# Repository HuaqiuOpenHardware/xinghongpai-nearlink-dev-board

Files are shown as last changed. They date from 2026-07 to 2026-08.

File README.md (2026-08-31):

<h1 align="center">Xinghongpai NearLink Dev Board</h1>

<p align="center"><strong>星鸿派 · WS63V100 / Hi3863 星闪开源开发板</strong></p>

<p align="center">
  <a href="README_EN.md">English</a> |
  <strong>简体中文</strong>
</p>

<p align="center">
  <a href="https://p.eda.cn/d-1328625634846441472">原始项目</a> ·
  <a href="hardware/">硬件设计</a> ·
  <a href="hardware/bom/">BOM</a> ·
  <a href="firmware/">固件示例</a> ·
  <a href="downloads/MANIFEST.md">资料校验</a>
</p>

<p align="center">
  🛠️ <a href="https://github.com/HuaqiuOpenHardware/xinghongpai-nearlink-dev-board/issues/new/choose">提交问题</a>
  &nbsp;·&nbsp;
  🤝 <a href="CONTRIBUTING.md">参与贡献</a>
  &nbsp;·&nbsp;
  ⭐ <a href="https://github.com/HuaqiuOpenHardware/xinghongpai-nearlink-dev-board">收藏项目</a>
</p>

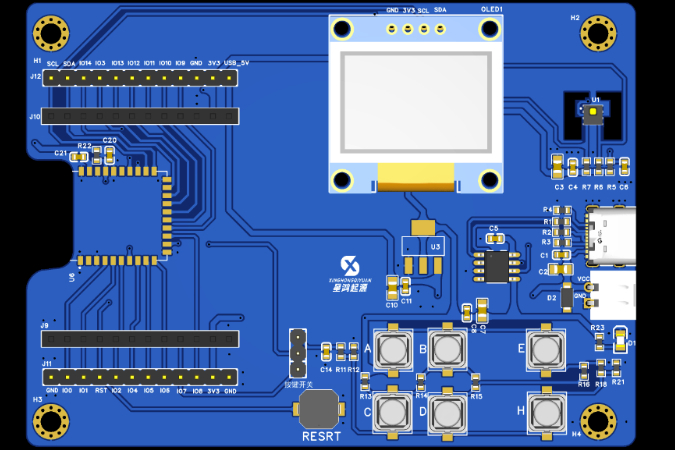
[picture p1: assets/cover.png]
星鸿派 WS63V100 星闪开源开发板


星鸿派是一款基于海思 **WS63V100 / Hi3863** 平台的开源开发板，支持 **星闪 NearLink（SLE）**、Wi-Fi 和 BLE，面向 OpenHarmony 学习、物联网原型、智能家电、环境监测与嵌入式教学。本仓库直接开放 KiCad 原理图与 PCB、BOM，以及 OpenHarmony / Hi3863 固件示例。

> 本仓库整理自华秋开源硬件社区公开项目。硬件许可证的具体 CERN-OHL 版本尚待项目方确认；复刻、修改或商用前请先阅读[许可证说明](#许可证说明)。

## 一眼看懂

| 项目 | 内容 |
| --- | --- |
| 主控平台 | HiSilicon WS63V100 / Hi3863 系列 |
| 无线连接 | NearLink SLE、Wi-Fi、BLE |
| 软件方向 | OpenHarmony / Hi3863 示例工程 |
| 板载资源 | 0.96 寸 OLED、6 个用户按键、复位按键、温湿度模块 |
| 硬件资产 | KiCad 工程、原理图、PCB、BOM |
| PCB 信息 | 约 96 mm × 70 mm，双层板（来自原项目页） |
| 适用人群 | 嵌入式开发者、创客、学生、教师与硬件研究者 |

## 开放资料

| 想找什么 | 仓库入口 | 当前状态 |
| --- | --- | --- |
| 原理图与 PCB 源文件 | [`hardware/kicad/`](hardware/kicad/) | 已提交，可直接查看与下载 |
| BOM 物料清单 | [`hardware/bom/`](hardware/bom/) | 已提交 XLSX |
| OpenHarmony / Hi3863 示例 | [`firmware/examples/`](firmware/examples/) | 已提交；依赖外部 SDK，不是独立工程 |
| 硬件与固件使用边界 | [`hardware/README.md`](hardware/README.md)、[`firmware/README.md`](firmware/README.md) | 已说明 |
| 原始资料来源与校验值 | [`downloads/MANIFEST.md`](downloads/MANIFEST.md) | 已记录 URL、大小和 SHA256 |
| 项目事实与来源 | [`PROJECT_FACTSHEET.md`](PROJECT_FACTSHEET.md) | 已整理 |
| 导入时的改动 | [`CHANGES_FROM_ORIGINAL.md`](CHANGES_FROM_ORIGINAL.md) | 已记录 |

原项目页提到 Gerber 文件，但首次导入使用的 PCB 下载包中没有独立 Gerber 制造文件。本仓库不把“页面提到”表述成“仓库已经提供”。

## 快速开始

### 查看或修改硬件

1. 打开 [`hardware/kicad/`](hardware/kicad/) 并下载 `.kicad_pro`、`.kicad_sch` 与 `.kicad_pcb` 文件。
2. 使用 KiCad 打开工程；复刻前同时核对原理图、PCB、[`BOM`](hardware/bom/) 和板卡实物版本。
3. 生成 Gerber、钻孔文件或贴片文件前，重新执行 ERC/DRC，并人工确认封装、替代料、电源与射频设计。

### 使用固件示例

1. 先阅读 [`firmware/README.md`](firmware/README.md)，确认示例并非可独立编译的完整 SDK。
2. 准备与示例匹配的 OpenHarmony / Hi3863（WS63）SDK 环境。
3. 从 GPIO、定时器、AHT20、OLED 等基础示例开始，再进入 Wi-Fi、TCP/UDP 与综合应用示例。
4. 提交问题时请提供 SDK / OpenHarmony 版本、示例目录、完整编译日志和板卡版本。

> 仓库尚未提供经过维护者复核的统一编译命令，因此这里不编造“一键编译”步骤。欢迎通过 Issue 或 Pull Request 补充可复现的环境说明。

## 固件示例方向

仓库中已有线程、定时器、互斥锁、信号量、消息队列、GPIO、AHT20、ADC、OLED、Wi-Fi、TCP/UDP，以及风扇、火焰检测、交通灯、继电器、温湿度等示例。具体文件以 [`firmware/examples/`](firmware/examples/) 为准。

推荐起点：

- [`11_aht20`](firmware/examples/11_aht20/)：AHT20 温湿度传感器
- [`13_adclight`](firmware/examples/13_adclight/)：ADC 光线采集
- [`14_easy_wifi`](firmware/examples/14_easy_wifi/)：Wi-Fi 连接与热点
- [`201_oled`](firmware/examples/201_oled/)：OLED 显示

## 仓库结构

```text
.
├── .github/                 # Issue 与 Pull Request 模板
├── assets/                 # 封面与实物图片
├── downloads/              # 原始下载地址、文件大小与 SHA256
├── firmware/
│   └── examples/           # OpenHarmony / Hi3863 固件示例
├── hardware/
│   ├── bom/                # BOM 物料清单
│   └── kicad/              # KiCad 原理图与 PCB 工程
├── LICENSES/               # 混合内容的许可证说明
├── CONTRIBUTING.md
├── PROJECT_FACTSHEET.md
├── README.md
└── README_EN.md
```

## 许可证说明

这个仓库包含硬件、固件和第三方资料，不能用一个未经确认的许可证覆盖全部内容：

- 原项目页的许可证字段显示 **CERN Open Hardware License**，但没有注明 CERN-OHL-S、W 或 P 等具体版本。
- 原项目页正文另有 Apache 2.0 与商用表述，两处口径并不完全一致。
- 多个固件文件保留了 HiHope Open Source Organization、HiSilicon 等来源的 Apache-2.0 版权头。
- 芯片文档、SDK、工具和原始压缩包可能适用各自的上游条款。

复刻、再分发、批量制造或商业化前，请阅读 [`LICENSE`](LICENSE) 与 [`LICENSES/README.md`](LICENSES/README.md)，并向项目方确认硬件许可证的准确版本。不要删除文件内已有的版权与许可证声明。

## 参与项目

- 硬件问题：使用 Hardware Issue 模板，注明板卡版本、测量结果、照片与复现步骤。
- 固件问题：使用 Firmware Issue 模板，注明 SDK / OpenHarmony 版本和完整日志。
- 提交修改：先阅读 [`CONTRIBUTING.md`](CONTRIBUTING.md)，并说明 BOM、硬件、固件和许可证影响。
- 安全问题：不要在公开 Issue 中提交 Wi-Fi 密码、密钥或生产设备凭据，详见 [`SECURITY.md`](SECURITY.md)。

## 来源与搜索别名

原始项目：华秋开源硬件社区「[星鸿派-星闪开发板](https://p.eda.cn/d-1328625634846441472)」。

相关名称：星闪、NearLink、SLE、SparkLink、WS63、WS63V100、Hi3863、HiSilicon、OpenHarmony、open-source hardware、development board、schematic、PCB、BOM、KiCad。

---

## 获取帮助与加入交流

如果你正在查找星闪开发资料、搭建 OpenHarmony / Hi3863 环境、复刻硬件，或希望交流项目使用与二次开发，可以添加 **华秋开源硬件小助手**。

添加后可获取：

- 星鸿派项目资料导航与更新提醒
- 开源硬件交流群入群方式
- 社区活动、试用与共创信息
- Issue 提交和项目反馈指引

<p align="center">
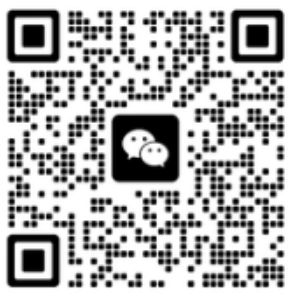
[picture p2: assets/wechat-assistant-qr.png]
华秋开源硬件小助手微信二维码
  
</p>

<p align="center"><strong>微信扫码添加小助手</strong></p>

<p align="center">添加时建议备注“星鸿派”，方便更快对接相关资料与交流群。</p>

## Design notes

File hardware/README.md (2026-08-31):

# Hardware | 硬件设计

This directory contains the KiCad hardware source files and BOM for the Xinghongpai NearLink development board.

本目录保存星鸿派 WS63V100 / Hi3863 星闪开发板的 KiCad 原理图、PCB 与 BOM。制造或修改前请同时核对原理图、PCB、BOM 和实际板卡版本。

## Files

- `kicad/*.kicad_pro`: KiCad project.
- `kicad/*.kicad_sch`: Schematic source.
- `kicad/*.kicad_pcb`: PCB layout source.
- `bom/BOM_Board1_Schematic1_2026-01-09.xlsx`: Bill of materials.

## Notes

The p.eda.cn page describes a 96 mm x 70 mm two-layer PCB. Gerber files were mentioned on the page but were not present as separate files in the downloaded PCB zip used for this import.

Before fabrication:

1. Open the complete project rather than a single schematic or PCB file.
2. Re-run ERC/DRC with the KiCad version used for your modification.
3. Verify footprints, alternative parts, connector orientation, power rails and RF-related layout against the intended board revision.
4. Generate fresh Gerber, drill, position and BOM outputs from the reviewed source. Do not treat generated files from an unknown revision as authoritative.
5. Record material substitutions and board changes in the Pull Request.

The presence of source files is not evidence that a modified board has been fabricated or electrically validated. Clearly label unverified derivatives.

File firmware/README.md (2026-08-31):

# Firmware Examples | 固件示例

The `examples/` directory contains OpenHarmony / Hi3863 sample applications from the original `02-程序源码.zip` package.

These examples reference an external OpenHarmony / HiSilicon WS63 SDK tree and are not expected to build standalone from this repository. Keep third-party SDKs outside this repo unless their license explicitly allows redistribution.

这些示例依赖仓库外部的 OpenHarmony / Hi3863（WS63）SDK，不能把本目录当成可独立编译的完整工程。仓库目前没有经过维护者复核的统一 SDK 版本和一键编译命令。

## Before using an example

1. Record the SDK and OpenHarmony version you are using.
2. Read the example's `BUILD.gn`, `CMakeLists.txt` or local README before copying it into an SDK tree.
3. Check GPIO, I2C, ADC, PWM and other pin assignments against your physical board revision.
4. Replace all network credentials with local test values and never commit real passwords or keys.
5. Capture the complete build command and log when reporting a problem.

## Suggested learning order

- Basic OS primitives: `00_thread`, `01_timer`, `03_mutex`, `04_semaphore`, `05_message`
- Board peripherals: `101_gpioled`, `11_aht20`, `13_adclight`, `201_oled`
- Networking: `14_easy_wifi`, `15_tcpclient`, `16_tcpserver`, `17_udpclient`, `18_udpserver`
- Integrated applications: directories in the `100`, `200` and `300` series

Directory names reflect the imported source package and do not imply that every example has been independently tested in this repository.

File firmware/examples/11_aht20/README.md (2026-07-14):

# 润和星闪派物联网开发套件--I2C（i2c_aht20）

hihope_illustration

[润和星闪派物联网开发套件](https://item.taobao.com/item.htm?id=816685710481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) 基于海思WS63E解决方案的一套软硬件组合的综合性开发套件。

wifi_iot

## 一、I2C API

| API名称 | 说明 |
| --- | --- |
| I2cInit (WifiIotI2cIdx id, unsigned int baudrate) | 用指定的波特速率初始化I2C设备 |
| I2cDeinit (WifiIotI2cIdx id) | 取消初始化I2C设备 |
| I2cWrite (WifiIotI2cIdx id, unsigned short deviceAddr, const WifiIotI2cData *i2cData) | 将数据写入I2C设备 |
| I2cRead (WifiIotI2cIdx id, unsigned short deviceAddr, const WifiIotI2cData *i2cData) | 从I2C设备中读取数据 |

## 二、Aht20 API

本样例提供了一个鸿蒙AHT20数字温湿度传感器驱动库，其功能如下：

* 使用Harmony OS的IoT硬件接口;
* 接口简洁易于使用、易于移植;
* 内置了测试程序，可直接进行测试;

| API名称 | 说明 |
| --- | --- |
| uint32_t AHT20_Calibrate(void) | 校准，成功返回0 |
| uint32_t AHT20_StartMeasure(void) | 触发测量，成功返回0 |
| uint32_t AHT20_GetMeasureResult(float* temp, float* humi) | 读取测量结果，成功返回0 |

## 三、如何编译

1. 将11_aht20目录复制到openharmony源码的`applications\sample\wifi-iot\app`目录下，
2. 修改openharmony源码的`applications\sample\wifi-iot\app\BUILD.gn`文件，将其中的 `features` 改为：

```
    features = [
        ...
        "11_aht20:i2c_demo",
        ...
    ]
```
3. 在`device\soc\hisilicon\ws63v100\sdk\build\config\target_config\ws63\config.py`文件中，找到`'ws63-liteos-app'`部分，在其`'ram_component'`中，添加以下代码：
```
"i2c_demo"
```

4. 在`device\soc\hisilicon\ws63v100\sdk\libs_url\ws63\cmake\ohos.cmake`文件中，找到`"ws63-liteos-app"`部分，在其`set(COMPONENT_LIST`部分，添加以下代码：
```
"i2c_demo"
```
5. 在openharmony sdk根目录目录执行：`rm -rf out && hb set -p nearlink_dk_3863 && hb build -f`

## 四、运行结果

烧录文件后，按下reset按键，程序开始运行，串口工具会输出测量后的温湿度数据

### 【套件支持】

##### 1. 套件购买  https://item.taobao.com/item.htm?id=816685710481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

##### 2. 技术资料

- Gitee码云网站（使用说明书、规格说明书、OpenHarmony开发案例等） **https://gitee.com/hihopeorg_group/near-link**
- fbb_ws63代码仓（SDK包、技术文档下载）**https://gitee.com/HiSpark/fbb_ws63**

##### 3. 互动交流
- 海思社区星闪专区-论坛 **https://developers.hisilicon.com/forum/0133146886267870001**

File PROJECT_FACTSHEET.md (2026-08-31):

# Project Factsheet

| Field | Value |
| --- | --- |
| Project | 星鸿派-星闪开发板 |
| English repo name | xinghongpai-nearlink-dev-board |
| Original URL | https://p.eda.cn/d-1328625634846441472 |
| Published on p.eda.cn | 2026-01-15 13:37:14 |
| Main controller | HiSilicon Hi3863 / WS63V100 series |
| Connectivity | Wi-Fi, BLE, SLE / NearLink |
| OS target | OpenHarmony |
| PCB | 96 mm x 70 mm, 2-layer |
| Hardware source | KiCad project, schematic and PCB |
| BOM | Included as XLSX |
| Firmware | OpenHarmony / Hi3863 examples |
| Page license field | CERN Open Hardware License |
| Page body license statement | Apache 2.0 |
| License status | Exact CERN-OHL hardware variant requires project-owner confirmation |
| Repository owner | HuaqiuOpenHardware |
| Repository | xinghongpai-nearlink-dev-board |

## Discovery aliases

星闪 / NearLink / SLE / SparkLink / WS63 / WS63V100 / Hi3863 / HiSilicon / OpenHarmony / development board / open-source hardware / schematic / PCB / BOM / KiCad

## Evidence boundary

This factsheet summarizes the imported project page and repository files. It does not claim independent validation of radio range, power consumption, environmental limits, firmware compatibility or manufacturing readiness.

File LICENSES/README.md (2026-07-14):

# License Notes

This repository is a mixed open hardware / firmware import from the public p.eda.cn project page for "星鸿派-星闪开发板".

## Hardware

The p.eda.cn license field states "CERN Open Hardware License". The specific CERN-OHL variant, such as S, W or P, was not provided in the page metadata captured for this import. Treat hardware redistribution as pending license-version confirmation before manufacturing or publishing modified derivatives.

## Firmware

Many firmware files include Apache License 2.0 headers from HiHope Open Source Organization and HiSilicon. The Apache-2.0 license text is included as `Apache-2.0.txt` when available.

## Original archives and vendor documents

`downloads/MANIFEST.md` records the public p.eda.cn download URLs and SHA256 checksums for the original packages. SDK and vendor documentation archives may contain third-party content; downstream users should follow the upstream terms included in those packages.

## Page inconsistency

The page content also says the project adopts Apache 2.0 for commercial reuse. Because the page-level license field and page body are not fully aligned for hardware licensing, this repository keeps the notices explicit instead of collapsing everything into one license.

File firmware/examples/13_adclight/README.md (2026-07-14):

# 润和星闪派物联网开发套件--ADC（光敏电阻）

hihope_illustration

[润和星闪派物联网开发套件](https://item.taobao.com/item.htm?id=816685710481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) 基于海思WS63E解决方案的一套软硬件组合的综合性开发套件。

wifi_iot

## 一、OLED与主控芯片引脚的对应关系

炫彩板光敏电阻对应核心板GPIO9(ADC2)

## 二、如何编译

1. 将13_adclight目录复制到openharmony源码的`applications\sample\wifi-iot\app`目录下，
2. 修改openharmony源码的`applications\sample\wifi-iot\app\BUILD.gn`文件，将其中的 `features` 改为：

```
    features = [
        ...
        "13_adclight:adc_light_demo",
        ...
    ]
```
3. 在`device\soc\hisilicon\ws63v100\sdk\build\config\target_config\ws63\config.py`文件中，找到`'ws63-liteos-app'`部分，在其`'ram_component'`中，添加以下代码：
```
"adc_light_demo"
```

4. 在`device\soc\hisilicon\ws63v100\sdk\libs_url\ws63\cmake\ohos.cmake`文件中，找到`"ws63-liteos-app"`部分，在其`set(COMPONENT_LIST`部分，添加以下代码：
```
"adc_light_demo"
```
5. 在openharmony sdk根目录目录执行：`rm -rf out && hb set -p nearlink_dk_3863 && hb build -f`

6. 如果编译失败，可以用串口助手，波特率设置为115200，发送AT指令(AT+SYSINFO\n)给开发板，如果返回的sdk版本低于SDK Version:1.10.102，需要替换一下adc相关的驱动文件，具体步骤参考adc_driver目录下替换文件步骤.txt

## 三、运行结果

烧录文件后，按下reset按键，程序开始运行，用手遮挡完全遮挡炫彩灯板上的光敏电阻，串口会打印一段时间的高电平数值，移开遮挡，串口会打印低电平数值。

### 【套件支持】

##### 1. 套件购买  https://item.taobao.com/item.htm?id=816685710481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

##### 2. 技术资料

- Gitee码云网站（使用说明书、规格说明书、OpenHarmony开发案例等） **https://gitee.com/hihopeorg_group/near-link**
- fbb_ws63代码仓（SDK包、技术文档下载）**https://gitee.com/HiSpark/fbb_ws63**

##### 3. 互动交流
- 海思社区星闪专区-论坛 **https://developers.hisilicon.com/forum/0133146886267870001**

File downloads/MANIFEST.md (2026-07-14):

# Original Download Manifest

Downloaded from the public p.eda.cn project page on 2026-07-14.
Large original archives are listed here instead of committed to Git history.

| Suggested local filename | Original filename | Bytes | SHA256 | Source |
| --- | --- | ---: | --- | --- |
| `01-xinghongpai-pcb.zip` | 01-星鸿派PCB.zip | 2084257 | `b765e80b18654c105c2079579242a03b7792638cc49ba510ce236c5e1ef5bfdf` | https://file1.huaqiu.com/web3/M00/48/C5/wKgZO2ly4ZGACJmXAB_Nofk7ZP8226.zip |
| `bom-2026-01-09.xlsx` | BOM_Board1_Schematic1_2026-01-09.xlsx | 13194 | `7dfdf15d19e44aa473998f1a41473c7713a62fab5a959dcc6f8dc81abec134c2` | https://file1.huaqiu.com/web3/M00/47/61/wKgZPGloVEqAFqJ2AAAzikkFFWU75.xlsx |
| `02-firmware-source.zip` | 02-程序源码.zip | 588959 | `ba52f00a5f157a4ca00100fa9ff8f750dab6bbe26f38795a7b5fd48a5d6bdcf7` | https://file1.huaqiu.com/web3/M00/48/C3/wKgZPGly4ECAKcdRAAj8n2G8QeY032.zip |
| `03-software-materials.zip` | 03-软件资料.zip | 11491575 | `581733ee7b2d679af3b7a50aa9e28f6ba4d0a471a8af4fe804eafc4ad1d431a7` | https://file1.huaqiu.com/web3/M00/48/C5/wKgZO2ly4FqANQWVAK9Y94BYe_Y757.zip |
| `04-course-documents.zip` | 04-课程文档.zip | 5325991 | `e247d37dae3311ed46612e51cb38a603ee40b18a3dc62cd049522f13e51aa0c9` | https://file1.huaqiu.com/web3/M00/48/C3/wKgZPGly4GCAD1TOAFFEpx-0sTY659.zip |
| `05-hispark-sdk-non-oh.zip` | 05-Hispark官方SDK方式（非OH）.zip | 3311853 | `8d67a0d5b3440f28f9779a69982212e576bd974ca63119f511d35917c8b14484` | https://file1.huaqiu.com/web3/M00/48/C3/wKgZPGly4GiAC9zeADKI7RaFW04333.zip |
| `06-ws63-official-documents.zip` | 06-WS63系列官方文档.zip | 22855597 | `9caa4624ff83f06b7a05d71526a10d64285c71d976740c0ff7624067d7fd837c` | https://file1.huaqiu.com/web3/M00/48/C3/wKgZPGly4JOAHNAmAVy_rQVX9NY285.zip |

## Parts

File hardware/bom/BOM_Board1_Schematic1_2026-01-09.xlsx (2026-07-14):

No. | Quantity | Comment | Designator | Footprint | Value | Manufacturer Part | Manufacturer | Add into BOM | Convert to PCB | Supplier | Supplier Part
1 | 6 | TS665WS 250gf | A,B,C,D,E,H | SW-SMD_L6.0-W6.0-LS6.6 |  | TS665WS 250gf | SHOU HAN(首韩) | yes | yes | LCSC | C6798384
2 | 7 | 100nF | C1,C4,C5,C8,C11,C14,C20 | C0603 | 100nF | CL10B104KB8NNNC | SAMSUNG(三星) | yes | yes | LCSC | C1591
3 | 4 | 22uF | C2,C3,C7,C10 | C0805 | 22uF | CL21A226MAQNNNE | SAMSUNG(三星) | yes | yes | LCSC | C45783
4 | 2 | 4.7uF | C6,C21 | C0603 | 4.7uF | CL10A475KO8NNNC | SAMSUNG(三星) | yes | yes | LCSC | C19666
5 | 1 | WAFER-XH254WZ-2AM | CN6 | CONN-TH_2P-P2.50_WAFER-XH254WZ-2A |  | WAFER-XH254WZ-2AM | HANBO(汉博) | yes | yes | LCSC | C22751831
6 | 1 | NCD0805R1 | D1 | LED0805-R-RD |  | NCD0805R1 | 国星光电 | yes | yes | LCSC | C84256
7 | 1 | SMF12CA | D2 | SOD-123FL_L3.0-W1.8-LS3.7-BI |  | SMF12CA | Littelfuse(美国力特) | yes | yes | LCSC | C1851360
8 | 4 | TP | H1,H2,H3,H4 | HOLE-3.2X5.5 |  |  |  | yes | yes
9 | 2 | KH-2.54FH-1X12P-H8.5 | J9,J10 | HDR-TH_12P-P2.54-V-F |  | KH-2.54FH-1X12P-H8.5 | kinghelm(金航标) | yes | yes | LCSC | C2905419
10 | 2 | X6511WV-12H-C60D30 | J11,J12 | HDR-TH_12P-P2.54-V-M |  | X6511WV-12H-C60D30 | XKB Connection(中国星坤) | yes | yes | LCSC | C725944
11 | 1 | HS96L03W2C03 | OLED1 | OLED-TH_L27.8-W27.2-P2.54_C9900033791 |  | HS96L03W2C03 | HS(汉昇) | yes | yes | LCSC | C5248080
12 | 2 | 0Ω | R1,R2 | R0603 | 0Ω | 0603WAF0000T5E | UNI-ROYAL(厚声) | yes | yes | LCSC | C21189
13 | 2 | 5.1kΩ | R3,R4 | R0603 | 5.1kΩ | 0603WAF5101T5E | UNI-ROYAL(厚声) | yes | yes | LCSC | C23186
14 | 1 | 470Ω | R5 | R0603 | 470Ω | 0603WAF4700T5E | UNI-ROYAL(厚声) | yes | yes | LCSC | C23179
15 | 2 | 10kΩ | R6,R7 | R0603 | 10kΩ | 0603WAF1002T5E | UNI-ROYAL(厚声) | yes | yes | LCSC | C25804
16 | 1 | 1kΩ | R11 | R0603 | 1kΩ | 0603WAF1001T5E | UNI-ROYAL(厚声) | yes | yes | LCSC | C21190
17 | 2 | 100kΩ | R12,R22 | R0603 | 100kΩ | 0603WAF1003T5E | UNI-ROYAL(厚声) | yes | yes | LCSC | C25803
18 | 7 | 300Ω | R13,R14,R15,R16,R18,R21,R23 | R0603 | 300Ω | 0603WAF3000T5E | UNI-ROYAL(厚声) | yes | yes | LCSC | C23025
19 | 2 | 4.7kΩ | R19,R20 | R0603 | 4.7kΩ | 0603WAF4701T5E | UNI-ROYAL(厚声) | yes | yes | LCSC | C23162
20 | 1 | OS4D502110 | RESRT | SW-SMD_L6.0-W6.0-P6.00-LS6.8 |  | OS4D502110 | SAMZO(三佐) | yes | yes | LCSC | C42402921
21 | 1 | AHT20 | U1 | SENSOR-SMD_L3.0-W3.0-P1.00-BR |  | AHT20 | 广州奥松 | yes | yes | LCSC | C2757850
22 | 1 | CH340N | U2 | SOP-8_L4.9-W3.9-P1.27-LS6.0-BL |  | CH340N | WCH(南京沁恒) | yes | yes | LCSC | C2977777
23 | 1 | AMS1117-3.3 | U3 | SOT-223-3_L6.5-W3.4-P2.30-LS7.0-BR |  | AMS1117-3.3 | AMS | yes | yes | LCSC | C6186
24 | 1 | F63VA01 | U6 | F63VA01 |  |  |  | yes | yes |  |  | WiFi6模组/星闪模组MYF-F63VA01 海思WS63/Hi3863 蓝牙模组-淘宝网 (https://item.taobao.com/item.htm?abbucket=6&id=970236105946&ns=1&skuId=6090171006115&xxc=taobaoSearch)
25 | 1 | HX TYPE-C 16PIN | Z1 | TYPE-C-SMD_HX-TYPE-C-16PIN |  | HX TYPE-C 16PIN | hanxia(韩下) | yes | yes | LCSC | C5178539
26 | 1 | PZ254V-11-03P | 按键开关 | HDR-TH_3P-P2.54-V-M |  | PZ254V-11-03P | XFCN(兴飞) | yes | yes | LCSC | C2937625

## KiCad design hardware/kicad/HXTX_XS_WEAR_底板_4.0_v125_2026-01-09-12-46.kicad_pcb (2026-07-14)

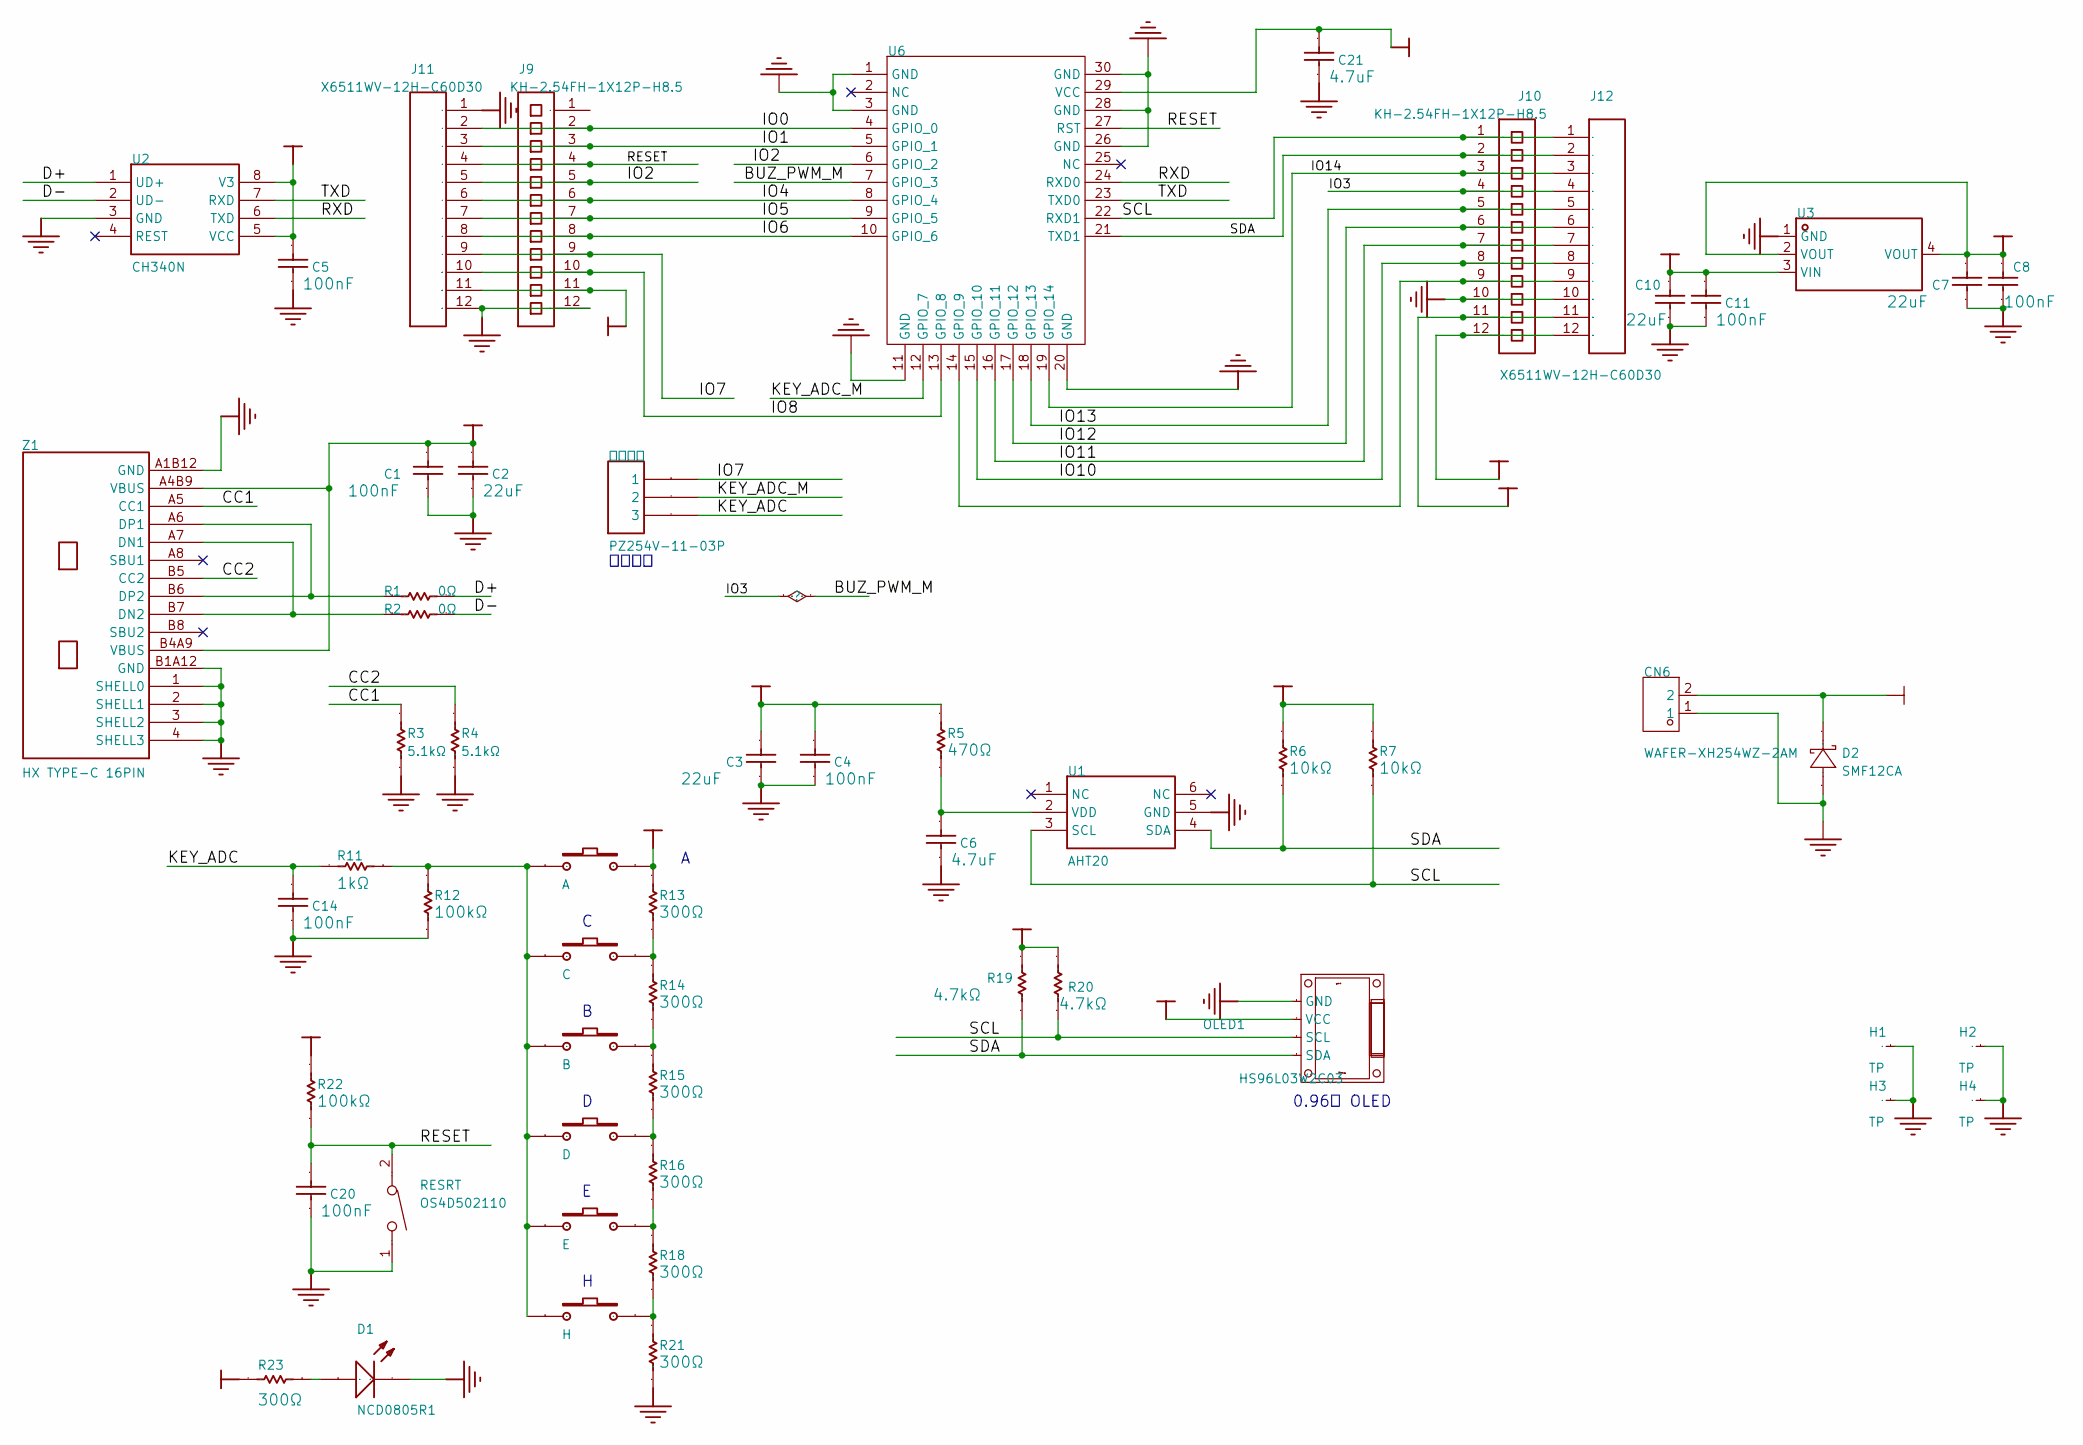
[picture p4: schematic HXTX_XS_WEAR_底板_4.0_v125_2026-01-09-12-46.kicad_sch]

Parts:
A: TS665WS 250gf; SW-SMD_L6.0-W6.0-LS6.6; Manufacturer Part TS665WS 250gf; LCSC Part Name 无声按键开关 6*6*5mm 250G
B: TS665WS 250gf; SW-SMD_L6.0-W6.0-LS6.6; Manufacturer Part TS665WS 250gf; LCSC Part Name 无声按键开关 6*6*5mm 250G
C: TS665WS 250gf; SW-SMD_L6.0-W6.0-LS6.6; Manufacturer Part TS665WS 250gf; LCSC Part Name 无声按键开关 6*6*5mm 250G
C1, C4, C5, C8, C11, C14, C20: 100nF; C0603; Manufacturer Part CL10B104KB8NNNC; LCSC Part Name 100nF ±10% 50V
C2, C3, C7, C10: 22uF; C0603; Manufacturer Part CL21A226MAQNNNE; LCSC Part Name 22uF ±20% 25V
C6, C21: 4.7uF; C0603; Manufacturer Part CL10A475KO8NNNC; LCSC Part Name 4.7uF ±10% 16V
CN6: WAFER-XH254WZ-2AM; CONN-TH_2P-P2.50_WAFER-XH254WZ-2A; Manufacturer Part WAFER-XH254WZ-2AM; LCSC Part Name 1x2P 间距:2.54mm 弯插 系列:XH
D: TS665WS 250gf; SW-SMD_L6.0-W6.0-LS6.6; Manufacturer Part TS665WS 250gf; LCSC Part Name 无声按键开关 6*6*5mm 250G
D1: NCD0805R1; LED-0805; Manufacturer Part NCD0805R1; LCSC Part Name NCD0805R1
D2: SMF12CA; SOD-123FL_L3.0-W1.8-LS3.7-BI; Manufacturer Part SMF12CA; LCSC Part Name SMF12CA
E: TS665WS 250gf; SW-SMD_L6.0-W6.0-LS6.6; Manufacturer Part TS665WS 250gf; LCSC Part Name 无声按键开关 6*6*5mm 250G
H: TS665WS 250gf; SW-SMD_L6.0-W6.0-LS6.6; Manufacturer Part TS665WS 250gf; LCSC Part Name 无声按键开关 6*6*5mm 250G
H1, H2, H3, H4: TP; HOLE-3.2X5.5
J9, J10: KH-2.54FH-1X12P-H8.5; HDR-TH_12P-P2.54-V-F; Manufacturer Part KH-2.54FH-1X12P-H8.5; LCSC Part Name 间距:2.54mm 1x12P 直插
J11, J12: X6511WV-12H-C60D30; HDR-TH_12P-P2.54-V-M; Manufacturer Part X6511WV-12H-C60D30; LCSC Part Name 1x12P 间距:2.54mm 方针
OLED1: HS96L03W2C03; 0.96OLED_4P; Manufacturer Part HS96L03W2C03; LCSC Part Name 0.96寸OLED显示屏窄白光IIC
R1, R2: 0Ω; R0603; Manufacturer Part 0603WAF0000T5E; LCSC Part Name 0Ω ±1% 100mW 厚膜电阻
R3, R4: 5.1kΩ; R0603; Manufacturer Part 0603WAF5101T5E; LCSC Part Name 5.1kΩ ±1% 100mW 厚膜电阻
R5: 470Ω; R0603; Manufacturer Part 0603WAF4700T5E; LCSC Part Name 470Ω ±1% 100mW 厚膜电阻
R6, R7: 10kΩ; R0603; Manufacturer Part 0603WAF1002T5E; LCSC Part Name 厚膜电阻 10kΩ ±1% 100mW
R11: 1kΩ; R0603; Manufacturer Part 0603WAF1001T5E; LCSC Part Name 1kΩ ±1% 100mW 厚膜电阻
R12, R22: 100kΩ; R0603; Manufacturer Part 0603WAF1003T5E; LCSC Part Name 100kΩ ±1% 100mW 厚膜电阻
R13, R14, R15, R16, R18, R21, R23: 300Ω; R0603; Manufacturer Part 0603WAF3000T5E; LCSC Part Name 300Ω ±1% 100mW 厚膜电阻
R19, R20: 4.7kΩ; R0603; Manufacturer Part 0603WAF4701T5E; LCSC Part Name 4.7kΩ ±1% 100mW 厚膜电阻
RESRT: OS4D502110; SW-SMD_L6.0-W6.0-P6.00-LS6.8; Manufacturer Part OS4D502110; LCSC Part Name 轻触开关6*6*5 翘两脚贴片硅胶柄无声开关 260gf
U1: AHT20; DFN-6_L3.0-W3.0-P1.00-BL; Manufacturer Part AHT20; LCSC Part Name AHT20
U2: CH340N; SOP-8; Manufacturer Part CH340N; LCSC Part Name USB2.0芯片CH340
U3: AMS1117-3.3; SOT-223-3_L6.5-W3.4-P2.30-LS7.0-BR; Manufacturer Part AMS1117-3.3; LCSC Part Name 输出3.3V 1A
U6: F63VA01
Z1: HX TYPE-C 16PIN; USB-C-SMD_TYPE-C16PIN; Manufacturer Part HX TYPE-C 16PIN; LCSC Part Name Type-C 母 卧贴
按键开关: PZ254V-11-03P; HDR-TH_3P-P2.54-V-M; Manufacturer Part PZ254V-11-03P; LCSC Part Name 1x3P 间距:2.54mm 方针 直插

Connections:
3V3: A.4, C3.2, C4.2, C5.2, C7.2, C8.2, C21.2, J9.11, J10.11, J11.11, J12.11, OLED1.2 (VCC), R5.2, R6.2, R7.2, R13.2, R19.2, R20.2, R22.2, R23.2, U2.5 (VCC), U2.8 (V3), U3.2 (VOUT), U3.4 (VOUT), U6.29 (VCC)
$1N2431: A.1, B.1, C.1, D.1, E.1, H.1, R11.1, R12.2
$1N2435: D1.1 (A), R23.1
$1N2450: D.4, R15.1, R16.2
$1N2451: C.4, R13.1, R14.2
$1N2465: C6.2, R5.1, U1.2 (VDD)
$1N2468: H.4, R18.1, R21.2
$1N2469: E.4, R16.1, R18.2
$1N2472: B.4, R14.1, R15.2
$1N2495: R2.1, Z1.A7 (DN1), Z1.B7 (DN2)
$1N2496: R1.1, Z1.A6 (DP1), Z1.B6 (DP2)
$1N10163: J10.9, J12.9, U6.14 (GPIO_9)
CC1: R3.2, Z1.A5 (CC1)
CC2: R4.2, Z1.B5 (CC2)
D+: R1.2, U2.1 (UD+)
D-: R2.2, U2.2 (UD-)
GND: C1.1, C2.1, C3.1, C4.1, C5.1, C6.1, C7.1, C8.1, C10.1, C11.1, C14.1, C20.1, C21.1, CN6.1, D1.2 (K), D2.1 (A), H1.1, H2.1, H3.1, H4.1, J9.12, J10.10, J11.1, J11.12, J12.10, OLED1.1 (GND), R3.1, R4.1, R12.1, R21.1, RESRT.1, U1.5 (GND), U2.3 (GND), U3.1 (GND), U6.1 (GND), U6.3 (GND), U6.11 (GND), U6.20 (GND), U6.26 (GND), U6.28 (GND), U6.30 (GND), Z1.1 (SHELL0), Z1.2 (SHELL1), Z1.3 (SHELL2), Z1.4 (SHELL3), Z1.A1B12 (GND), Z1.B1A12 (GND)
IO0: J9.2, J11.2, U6.4 (GPIO_0)
IO1: J9.3, J11.3, U6.5 (GPIO_1)
IO2: J9.5, J11.5, U6.6 (GPIO_2)
IO4: J9.6, J11.6, U6.8 (GPIO_4)
IO5: J9.7, J11.7, U6.9 (GPIO_5)
IO6: J9.8, J11.8, U6.10 (GPIO_6)
IO7: J9.9, J11.9, 按键开关.1
IO8: J9.10, J11.10, U6.13 (GPIO_8)
IO10: J10.8, J12.8, U6.15 (GPIO_10)
IO11: J10.7, J12.7, U6.16 (GPIO_11)
IO12: J10.6, J12.6, U6.17 (GPIO_12)
IO13: J10.5, J12.5, U6.18 (GPIO_13)
IO14: J10.3, J12.3, U6.19 (GPIO_14)
KEY_ADC: C14.2, R11.2, 按键开关.3
KEY_ADC_M: U6.12 (GPIO_7), 按键开关.2
RESET: C20.2, J9.4, J11.4, R22.1, RESRT.2, U6.27 (RST)
RXD: U2.6 (TXD), U6.24 (RXD0)
SCL: J10.1, J12.1, OLED1.3 (SCL), R7.1, R20.1, U1.3 (SCL), U6.22 (RXD1)
SDA: J10.2, J12.2, OLED1.4 (SDA), R6.1, R19.1, U1.4 (SDA), U6.21 (TXD1)
TXD: U2.7 (RXD), U6.23 (TXD0)
USB_5V: C1.2, C2.2, C10.2, C11.2, CN6.2, D2.2 (K), J10.12, J12.12, U3.3 (VIN), Z1.A4B9 (VBUS), Z1.B4A9 (VBUS)

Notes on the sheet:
0.96寸 OLED
按键开关

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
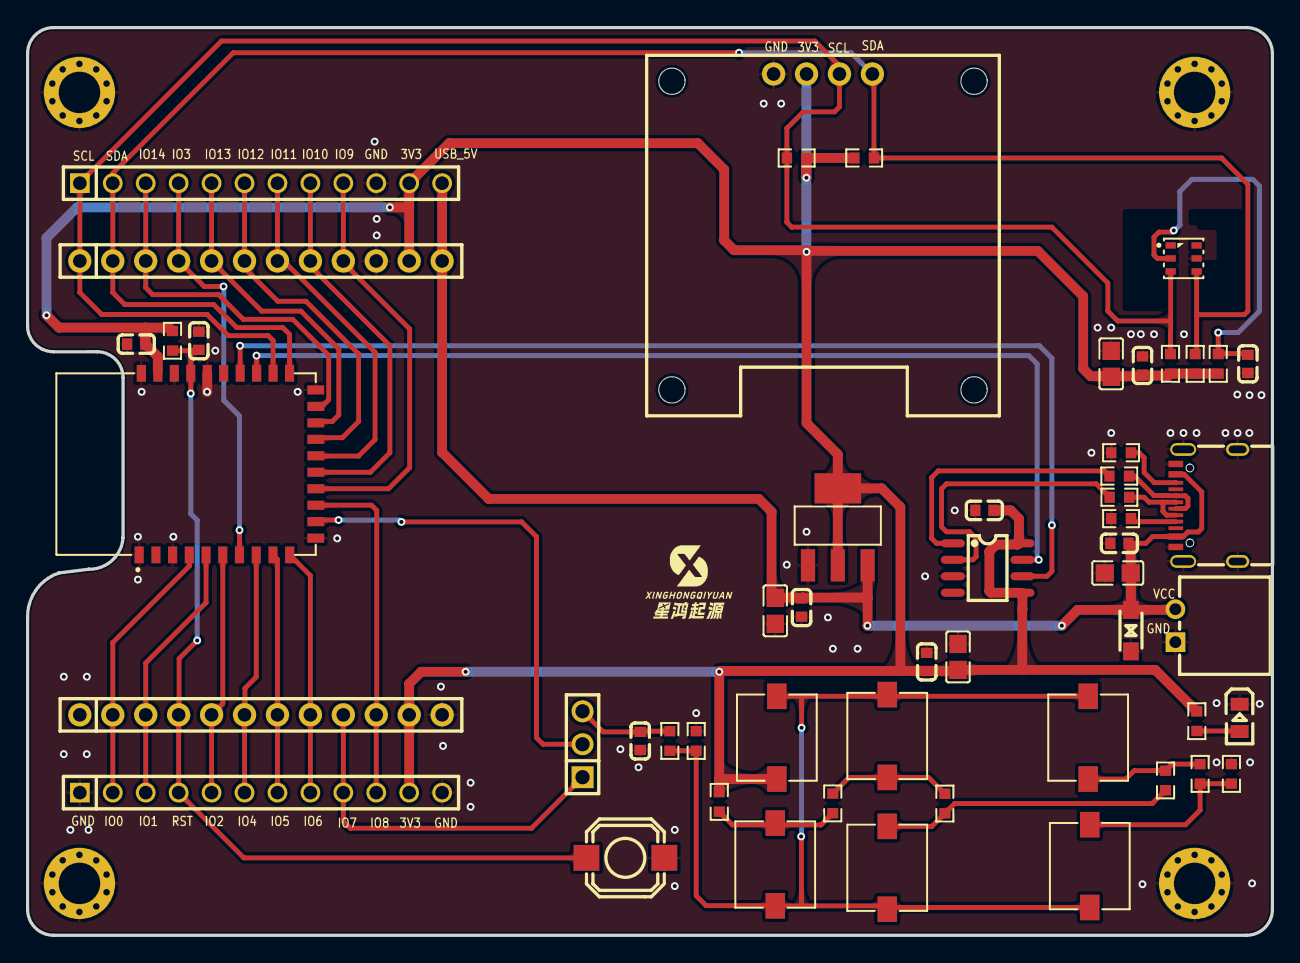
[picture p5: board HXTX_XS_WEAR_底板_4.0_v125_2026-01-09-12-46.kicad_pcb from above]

Board: 2 copper layers, 96.0 x 70.0 mm, 57 parts (0 on the bottom side), 39 nets.

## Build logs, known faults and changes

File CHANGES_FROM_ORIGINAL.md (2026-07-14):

# Changes From Original Import

This repository records the original downloadable archives in `downloads/MANIFEST.md`.

The extracted firmware examples were lightly sanitized before publishing to GitHub:

- Replaced demo Wi-Fi passwords such as `12345678`, `123456789` and `1234567890` with explicit placeholders.
- Kept the original archive URLs and checksums in `downloads/MANIFEST.md` so the source package can be verified against p.eda.cn.

No hardware source files were modified during the first import.

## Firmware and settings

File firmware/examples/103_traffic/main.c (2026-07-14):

/**
 * History: \n
 * 2025-10-17, Create file. \n
 */
#include <stdio.h>

#include <unistd.h>

#include "cmsis_os2.h"
#include "ohos_init.h"
#include "iot_gpio.h"

#include "gpio.h"
#include "pinctrl.h"
#include "systick.h"
#include "watchdog.h"

#include "./traffic_light/traffic_light.h"
#include "./key/key_demo.h"
#include "./segment_display/segment_display.h"

#define SEGMENT_THREAD_STACK_SIZE      0x1000
#define SEGMENT_THREAD_PRIO            18

static void *segment_thread(const char *arg)
{
    unused(arg);

    // 配置数码管引脚
    segment_display_config_t segment_display_config = {
        .seg_a = GPIO_11,
        .seg_b = GPIO_01,
        .seg_c = GPIO_06,
        .seg_d = GPIO_03,
        .seg_e = GPIO_14,
        .seg_f = GPIO_12,
        .seg_g = GPIO_07,
        .seg_dp = GPIO_10,
        .digit1 = GPIO_04,  // 十位
        .digit2 = GPIO_02   // 个位
    };
    // 初始化数码管
    func_segment_display_init(&segment_display_config);
    func_segment_display_show_number(00);

    uapi_systick_init();

    uint16_t count = 0;

    while (1)
    {
        func_segment_display_process(2);
        uapi_systick_delay_ms(2);

        if (++count >= 500)
        {
            count = 0;
            static uint8_t number = 0;
            func_segment_display_show_number(number);
            number = (number + 1) % 100;
        }
    }
    return NULL;
}

#define TEST_THREAD_STACK_SIZE      0x1000
#define TEST_THREAD_PRIO            17

static void *test_thread(const char *arg)
{
    unused(arg);

    printf("\r\n103_traffic\r\n");
    sleep(1); //等待uart2（gpio7,gpio8）初始化完成后，再设置GPIO7为gpio功能

    // 配置交通灯
    traffic_light_config_t traffic_ligtht_config = {
        .red_pin = GPIO_08,
        .yellow_pin = GPIO_09,
        .green_pin = GPIO_05
    };
    func_traffic_light_init(&traffic_ligtht_config);

    key_config_t key_config = {
        .pin = GPIO_00,
        .active_level = GPIO_LEVEL_LOW, // 低电平有效
        .debounce_time = 20,            // 20ms消抖
    };
    func_key_register(&key_config);

    osThreadAttr_t attr;

    attr.name = "segment_thread";
    attr.attr_bits = 0U;
    attr.cb_mem = NULL;
    attr.cb_size = 0U;
    attr.stack_mem = NULL;
    attr.stack_size = 2048;
    attr.priority = 25;

    if (osThreadNew((osThreadFunc_t) segment_thread, NULL, &attr) == NULL) {
        printf("[segment_thread] Falied to create GpioTask!\n");
    }

    uint16_t count_watchdog = 0;

    while (1)
    {
        func_key_process(10);
        osDelay(10);

        // 检查按键事件
        key_event_t event = func_key_get_event(GPIO_00);

        if (event == KEY_EVENT_PRESS)
        {
            printf("key pressed\r\n");
            func_traffic_light_set_all(true, true, true);
        } 
        else if (event == KEY_EVENT_RELEASE) 
        {
            printf("key released\r\n");
            func_traffic_light_off();
        }

        //喂看门狗
        count_watchdog++;
        if (count_watchdog >= 100)
        {
            uapi_watchdog_kick(); 
        }
    }
    
    return NULL;
}


static void test_entry(void)
{
    osThreadAttr_t attr;

    attr.name = "test_thread";
    attr.attr_bits = 0U;
    attr.cb_mem = NULL;
    attr.cb_size = 0U;
    attr.stack_mem = NULL;
    attr.stack_size = 2048;
    attr.priority = 25;

    if (osThreadNew((osThreadFunc_t) test_thread, NULL, &attr) == NULL) {
        printf("[test_thread] Falied to create GpioTask!\n");
    }
}

SYS_RUN(test_entry);

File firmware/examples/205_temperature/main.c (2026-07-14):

/**
 * History: \n
 * 2025-10-17, Create file. \n
 */
#include <stdio.h>
#include "app_init.h"
#include "common_def.h"

#include "osal_task.h"
#include "gpio.h"
#include "pinctrl.h"
#include "i2c.h"
#include "lwip/sockets.h"
#include "wifi_hotspot.h"
#include "cJSON.h"
#include "upg_porting.h"

#include "./aht20/aht20.h"
#include "./wifi/wifi_connect.h"

#define TEST_THREAD_STACK_SIZE      0x1000
#define TEST_THREAD_PRIO            17

#define SCL_PIN     17
#define SDA_PIN     18
#define PIN_MODE    2

#define SSID                    "YOUR_WIFI_SSID"
#define PASSWORD                "YOUR_WIFI_PASSWORD"
#define BOARDCAST_PORT          8000

static void *test_thread(const char *arg)
{
    unused(arg);
    printf("\r\n205_temperature\r\n");

    func_wifi_connect(SSID, PASSWORD);

    /* 广播设备tcp服务器的ip地址和端口 */
    // 在sock_fd 进行监听
    int sock_fd;
    int broadcastEnable = 1;

    printf("create socket start!\r\n");
    if ((sock_fd = socket(AF_INET, SOCK_DGRAM, 0)) == -1)
    {
        printf("create socket failed!\r\n");
        lwip_close(sock_fd);
    }
    printf("create socket end!\r\n");

    // 设置socket为广播模式
    if (setsockopt(sock_fd, SOL_SOCKET, SO_BROADCAST, &broadcastEnable, sizeof(broadcastEnable)) == -1)
    {
        printf("setsockopt(SO_BROADCAST) failed!\r\n");
        lwip_close(sock_fd);
    }
    printf("set broadcast option success!\r\n");

    // 服务器的地址信息
    struct sockaddr_in send_addr;
    socklen_t addr_length = sizeof(send_addr);

    // 初始化广播地址
    send_addr.sin_family = AF_INET;
    send_addr.sin_port = htons(BOARDCAST_PORT);
    send_addr.sin_addr.s_addr = inet_addr("255.255.255.255");
    addr_length = sizeof(send_addr);

    osal_msleep(500);

    // char send_data[128] = {0};
    char send_data[128] = "hello";

    uapi_pin_init();
    uapi_gpio_init();

    uint32_t baudrate = 400000;
    uint32_t hscode = 0x0;
    uapi_pin_set_mode(SCL_PIN, PIN_MODE);
    uapi_pin_set_mode(SDA_PIN, PIN_MODE);
    errcode_t ret = uapi_i2c_master_init(0, baudrate, hscode);
    if (ret != 0)
    {
        printf("uapi_i2c_master_init() failed, ret = %0x\r\n", ret);
    }

    // 检查AHT20的校准使能状态
    while (AHT20_Calibrate() != 0)
    {
        printf("AHT20_Calibrate() failed\r\n");
        osal_msleep(500); // 500ms后再判断设备是否复位成功
    }

    uint32_t retval = 0;
    float temp = 0;
    float humi = 0;
    char temp_str[20];  // 存储温度字符串
    char humi_str[20];  // 存储湿度字符串
    
    while (1)
    {
        retval = AHT20_StartMeasure();
        printf("AHT20_StartMeasure: %d\r\n", retval);
        retval = AHT20_GetMeasureResult(&temp, &humi);
        if (retval != 0)
        {
            printf("AHT20_GetMeasureResult() failed, ret = %d\r\n", retval);
        }
        else
        {
            // // 转换为字符串（保留2位小数）
            // sprintf(temp_str, "温度: %.2f °C", temp);
            // sprintf(humi_str, "湿度: %.2f %%", humi);
            // // 输出字符串
            // printf("%s, %s\r\n", temp_str, humi_str);

            // 转换为字符串（保留2位小数）
            sprintf(send_data, "temp: %.2f °C, humi: %.2f %%", temp, humi);

            // // 发送数据到广播地址
            // printf("sendto broadcast start! Data: %s\r\n", send_data);
            if (sendto(sock_fd, send_data, strlen(send_data), 0, (struct sockaddr *)&send_addr, addr_length) == -1) 
            {
                printf("sendto broadcast failed!\r\n");
            }
            else 
            {
                printf("sendto broadcast end!\r\n");
            }
        }

        osal_msleep(1000);
    }
    
    return NULL;
}


static void test_entry(void)
{
    osal_task *test_handle = NULL;
    osal_kthread_lock();
    test_handle = osal_kthread_create((osal_kthread_handler)test_thread, 0, "test_thread", TEST_THREAD_STACK_SIZE);
    if (test_handle != NULL)
    {
        osal_kthread_set_priority(test_handle, TEST_THREAD_PRIO);
    }
    osal_kthread_unlock();
}

app_run(test_entry);
